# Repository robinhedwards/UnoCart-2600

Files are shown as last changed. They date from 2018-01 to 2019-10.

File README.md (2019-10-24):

UnoCart-2600
============
The UnoCart-2600 is an open source SD-card multicart for the Atari 2600. Use the joystick or the SELECT/RESET keys
to navigate the SD card and select a title to play.

SD card should be formatted as FAT or FAT32.

The UnoCart-2600 can emulate most banking schemes with ROM sizes up to 64k and RAM sizes up to 32k.
(more description to follow)

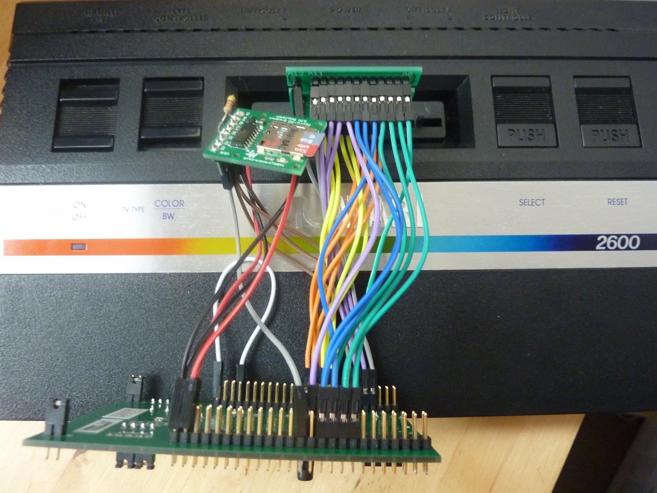
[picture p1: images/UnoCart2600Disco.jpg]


Hardware
--------
The UnoCart-2600 is based on my earlier UnoCart project for the Atari 8-bit. It can be built using a STM32F407 DISCOVERY board
connected to a small PCB to breakout the Atari 2600 cartridge signals.

An article describing how to build an UnoCart for the Atari 8-bit was published in
[Excel Magazine](http://excel-retro-mag.co.uk) issue #4. You can also get a PDF of the article [here](https://github.com/robinhedwards/UnoCart/blob/master/UnoCart_EXCEL4.pdf).

Building the cartridge for the 2600 is almost identical, with the same connections between D0-D7 and A0-A12, +5V and GND.
All the other connections to the breakout PCB can be skipped, since these signals are not present on the 2600 cartridge slot.

Obviously, you'll need a breakout board designed for the 2600 cartridge slot rather than the Atari 8-bit. The design files for the breakout PCB are hosted here and can be used to make your own copy of the PCB.

Remember to program your DISCO board with the UnoCart-2600 firmware, rather than the UnoCart firmware.

(better building instructions to follow)

The UnoCart-2600 menu can be set to display in NTSC, PAL or PAL60 as follows:
* By default, the firmware will be NTSC.
* Connect PC0 -> GND for PAL60
* Connect PC1 -> GND for PAL

Note that this is for the menu only, and has no effect after you have selected a cartridge to play.

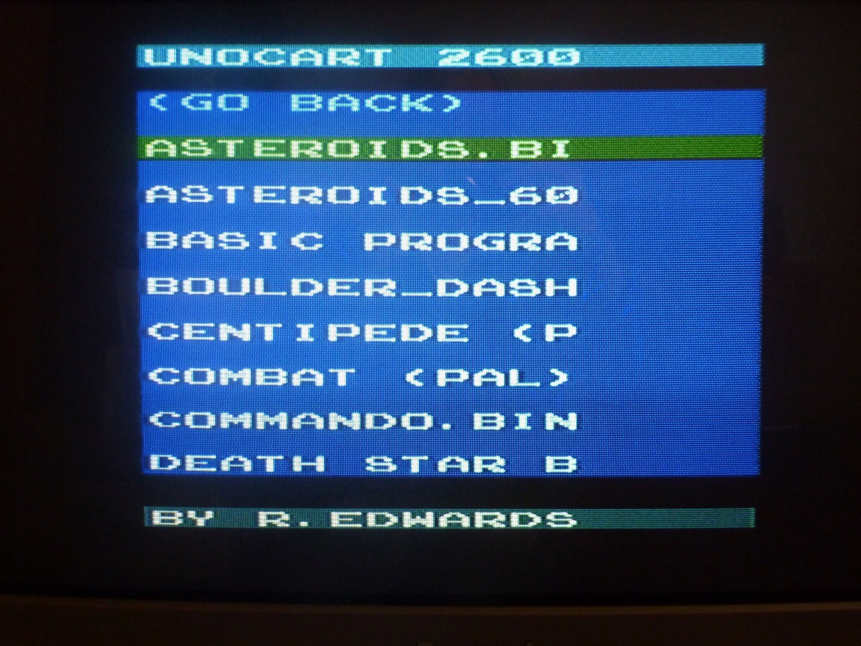
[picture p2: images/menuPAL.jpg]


Custom PCB
----------
I have also designed a custom PCB for the UnoCart-2600 pictured here. This is mainly to make it easier to get people
to test the design. The PCB design files are not currently public.

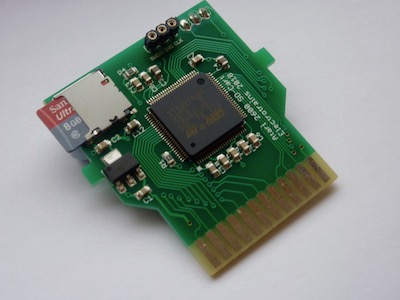
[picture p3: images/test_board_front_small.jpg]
Front of PCB when inserted in Atari

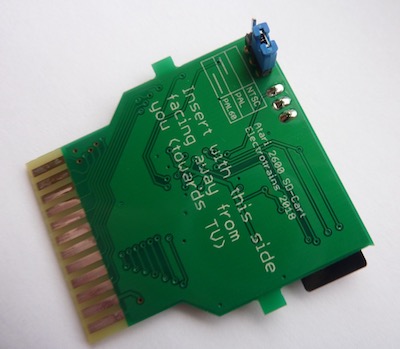
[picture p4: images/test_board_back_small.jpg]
Back of PCB when inserted in Atari


Firmware
--------
The UnoCart-2600 firmware is open source under a GPL license and my original firmware hosted here.
However, there is a newer version - see below.

New firmware
------------
I haven't had any time to develop the firmware further, but DirtyHairy & ZackAttack on the AtariAge forums
have added some great stuff to the firmware, including updating from SD card, support for Pink Panther prototype
cartridge and much more to come.

The releases of this new firmware can be found on [DirtyHairy's branch](https://github.com/DirtyHairy/UnoCart-2600/releases)

You'll need an ST-Link programmer the first time you update to this branch of the firmware. Subsequent updates can
done simply from the SD card.

Credits
-------
* Design, hardware and firmware by Robin Edwards (electrotrains at atariage)
* Additional work on firmware by Christian Speckner (DirtyHairy at atariage)

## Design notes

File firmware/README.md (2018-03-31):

The current UnoCart2600 firmware (v1.05)

For use with ST-Link device and STM32 ST-Link utility.

Changelog

* 2018-01-27 v1.0 Initial version.
* 2018-02-08 v1.02 Navigation bug fix + Pitfall II support
* 2018-03-21 v1.04 Supercharger support thanks to Christian Speckner
* 2018-03-31 v1.05 Now compatible with Atari 7800

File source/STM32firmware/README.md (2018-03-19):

Source code for the UnoCart2600 firmware.

# Building with Atollic Truestudio

Atollic Truestudio 6 project.
After building, firmware will be in the Debug subdirectory.

The various 2600 firmware ROMs (PAL/NTSC etc) are in include files. These can be rebuilt from the source code in the /source/Atari2600ROM/ directory. The convert.bat batch file will turn the binary files into header files. Add the "const" keyword so these will be stored in STM32F4 flash rather than RAM.

# Building from CLI

You can build and flash the firmware with the provided `Makefile`using the official
[ARM Cortex GNU toolchain](http://developer.arm.com/open-source/gnu-toolchain/gnu-rm)
and the open source [stlink tool suite](https://github.com/texane/stlink).

```
    $ make           # Build firware in build directory
    $ make flash     # Build and flash firmware
```

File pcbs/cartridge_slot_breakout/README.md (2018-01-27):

Eagle board file for Atari 2600 cartridge slot breakout PCB, which breaks out the cartridge slot to headers (male or female).

IMPORTANT - Make sure you insert the board the correct way round in your 2600. The picture below shows the correct orientation.

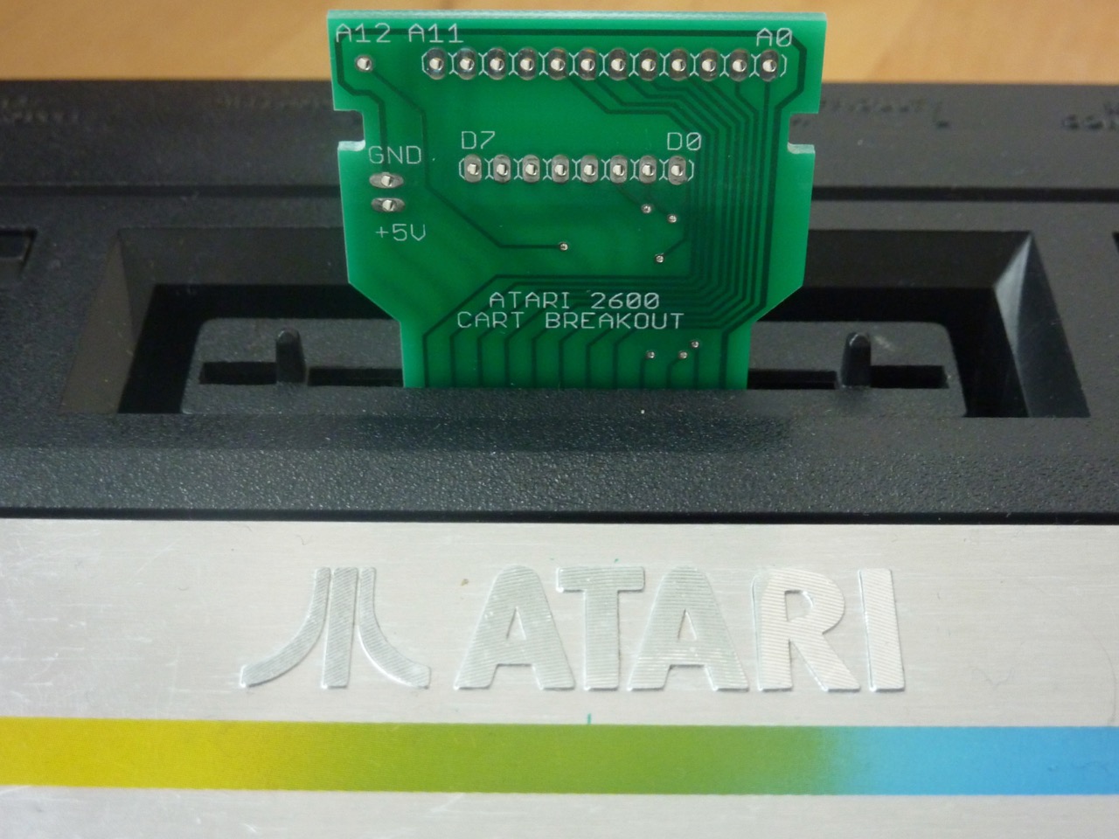
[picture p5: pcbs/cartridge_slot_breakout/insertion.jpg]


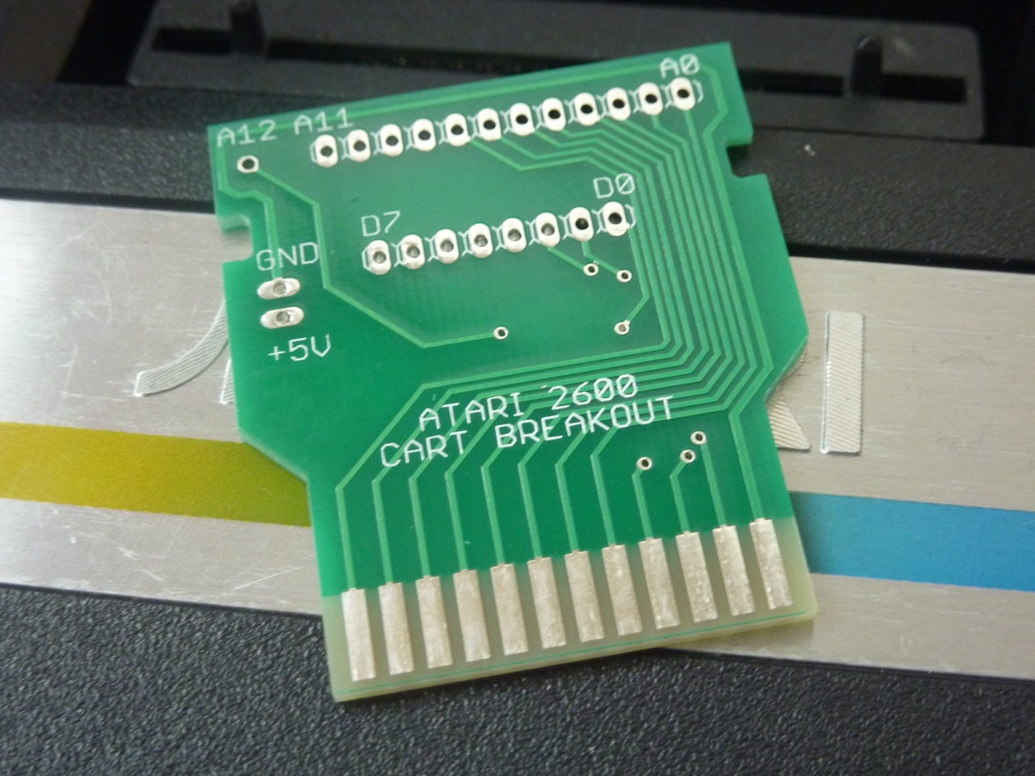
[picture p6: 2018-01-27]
images/breakout.jpg

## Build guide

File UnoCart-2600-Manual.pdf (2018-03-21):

# UNOCART-2600

# Instruction Manual

Revision 1.4 21/3/2018

Atari 2600 SD multi-cart

Quick Start
The UnoCart -2600 is an Atari cartridge emulator. It supports cartridges with up to 64k of ROM and 32k of RAM. First, copy BIN, ROM or A26 files to an SD card and insert it into the cartridge. Check the TV configuration jumper on the back of the board matches your TV system. Insert the cartridge in the Atari 2600. If the board is uncased, check you’ve got it the right way round (see picture). Power on the Atari and use the joystick to choose an item and the fire button to start it.

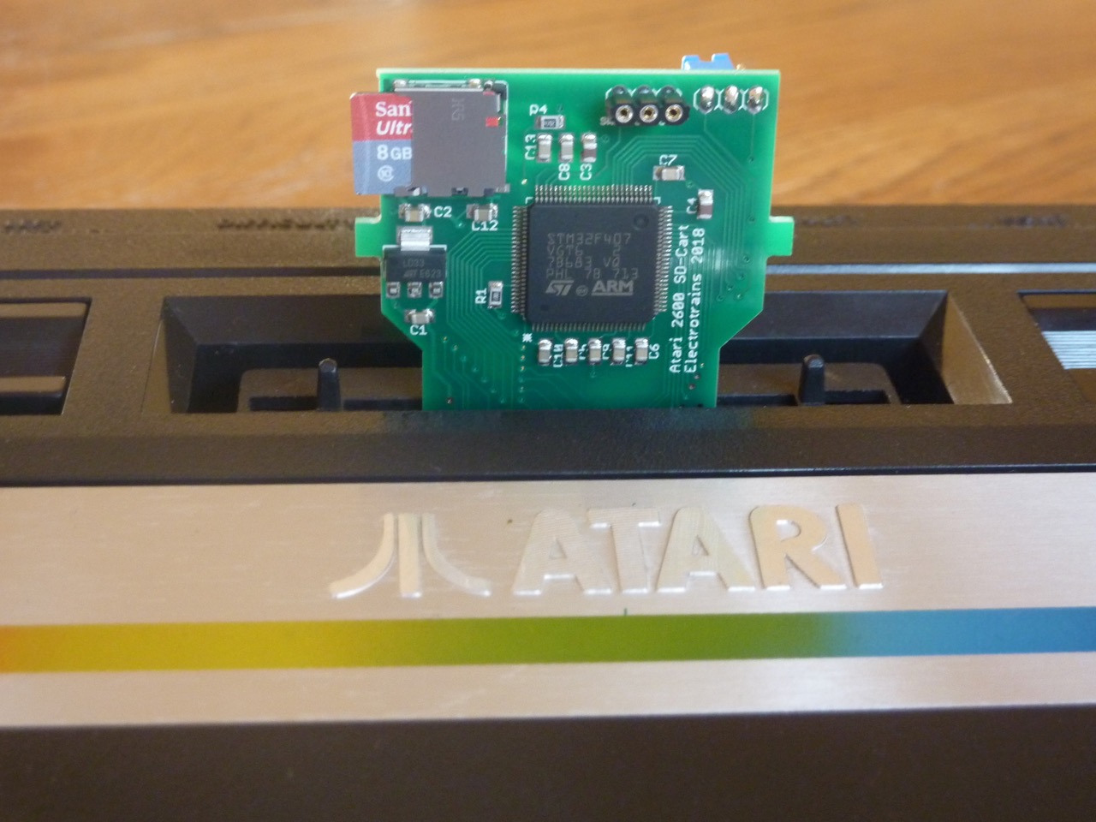
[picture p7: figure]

PAL/NTSC Configuration
The jumper on the back of the board allows you to select whether the cartridge uses NTSC or PAL/PAL60 for the built-in menu. You can remove the jumper completely if you are using a NTSC TV.
Note that this jumper only applies to the cartridge menu (and also to the Supercharger BIOS if you are using a Supercharger cartridge type). Once you select a ROM to emulate, the TV picture produced will be entirely dependent on the cartridge being emulated. In general there were separate PAL and NTSC versions of each cartridge – make sure you get the correct version.
SD Cards
SD cards should be formatted as FAT32. Newer SD cards may come formatted as exFAT. These can be used with the UnoCart-2600, but need to be re-formatted as FAT32 on your computer prior to use. Note that the UnoCart-2600 firmware will only show up to 80 items per directory. You can use directories to organise your files.

Menu

The menu allows you to navigate the files on the card and select a title to use. Joystick up and down will move through the items one at a time. You can also use joystick left and right to move to the previous or next page. Press fire to select an item. You can also use the SELECT button on the console to move to the next item, and RESET to select an item, if you don’t have a joystick plugged in.
Compatibility

The UnoCart-2600 should be able to emulate every cartridge released during the commercial life of the 2600. Newer homebrew titles should also be compatible with the UnoCart-2600, unless they use the DPC+ co-processor features specific to the Harmony/Melody cartridge. Note that the DPC support on the cartridge is not complete but it is sufficient to play Pitfall II.
Arcadia/Starpath Supercharger titles are emulated with the multi-load parts combined in a single file. Up to 256 loads are supported (2MB file). The Supercharger BIOS will use the TV type set by the UnoCart-2600 TV jumper. ROM Files

The UnoCart uses cartridge detection signatures from the Stella Atari 2600 emulator to auto-detect all common cartridge types. If a file has an extension of .BIN, .ROM or .A26 it will be auto-detected. If you want to force the cartridge to be emulated as a specific type, you can use the file extensions listed in the table below.

Cartridge Type | ROM | RAM | File Extension
2K | 2K | | .2K
4K | 4K | | .4K
F8 | 8K | | .F8
F8 SC | 8K | 128 bytes | .F8S
F6 | 16K | | .F6
F6 SC | 16K | 128 bytes | .F6S
F4 | 32K | | .F4
F4 SC | 32K | 128 bytes | .F4S
FE (Activision) | 8K | | .FE
3F (Tigervision) | <=64K | | .3F
3E | <=64K | <=32K | .3E
E0 (Parker Bros) | 8K | | .E0
0840 | 8K | | .084
CV (CommaVid) | 2K | 1K | .CV
EF | 64K | | .EF
EF SC | 64K | 128 bytes | .EFS
F0 | 64K | | .F0
FA (CBS RAM Plus) | 12K | 256 bytes | .FA
E7 (M-Network) | 16K | 2K | .E7
DPC (Pitfall II) | 8K+2K | | .DPC
Supercharger | 256 loads | | .AR

Firmware re-programming (advanced)

The board can be re-programmed using an ST-Link device. The programming header is at the top of the board. First connect the 3 pins to the equivalent pins on your ST-Link. You should then connect the ST-Link device to the USB port of your computer. You will also need to power the board – the easiest way to do this is to plug the board into your Atari 2600 and power on. The ST-Link software should then be able to connect to the STM32F407 and re-program the firmware.
The latest firmware is available on the project website: https://github.com/robinhedwards/UnoCart-2600

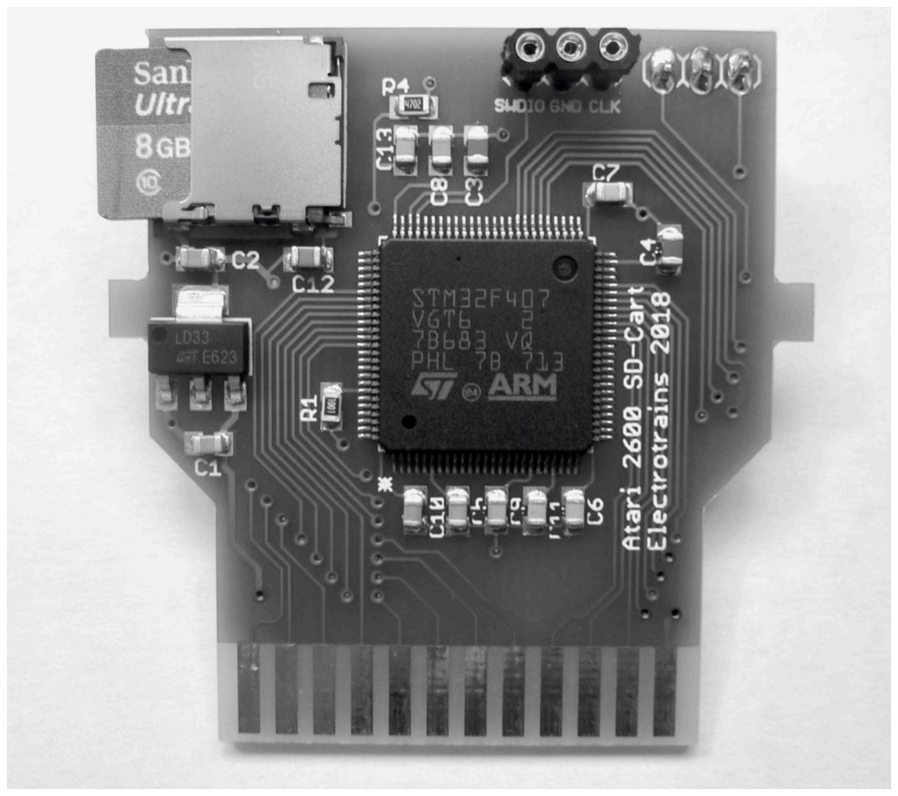
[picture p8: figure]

Pin | SWD | Function
1 | SWDIO | SWD I/O
2 | GND | GND
3 | SWCLK | SWD Clock

Microcontroller (advanced)
The UnoCart-2600 will be fitted with either a STM32F407VGT6 (1meg flash) or a STM32F407VET6 (512k flash) microcontroller. Please refer to your PCB to determine which one is present on your device. If you are developing new firmware for the cartridge, the table below shows the pins connected to the cartridge port & micro SD card slot.
STM32 Pin(s) | Cartridge Port | STM32 Pin(s) | Function
PD0...12 | A0…A12 | PB5 | MicroSD CS
PE8…15 | D0…D7 | PB13 (SPI2,2) | MicroSD CLK
PC0 | TV Jumper | PB14 (SPI2,2) | MicroSD DO
PC1 | TV Jumper | PB15 (SPI2,2) | MicroSD DI

Credits
Original idea, hardware and firmware by Robin Edwards (electrotrains at atariage).
Additional cartridge support and firmware additions by Christian Speckner (DirtyHairy at atariage).

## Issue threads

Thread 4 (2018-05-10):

Will the PCB files be made public?

Arduingo, 2018-05-10:
Great work, and thanks to make it public, are you going to release de PCB files? in case no, do you mind if someone else release his PCB design and link to this project?

robinhedwards, 2018-05-11:
The PCB design will be made public at some point in the future - I've been redesigning it to fit in a cart shell and use an SD card rather than a microSD.

These will initially be produced by MacRorie in the USA for sale, and possibly someone in europe too.
I'll update the page when this happens.

root42, 2019-05-20:
Would love to see this happen, or have the ability to buy it from someone in Europe. Any chance of progress on this?

ranger81, 2020-04-03:
@robinhedwards Is there any update on releasing the PCB files or schematics?
Thanks

TabajaraLabs, 2020-04-03:
Looking for the PCB files too =)

tdididit, 2020-04-03:
@robinhedwards If you agree I will make public my PCB design with USB ISP circuit addon

ranger81, 2020-04-03:
@tdididit Would be greatly appreciated. Schematic would be fine for me - also I would be very interested about the USB ISP circuit addon. Please let me know, if your schematics are available somewhere.

tdididit, 2020-04-03:
@ranger81 I didn't seen a schematics, but only thing what you need to make it is reading with understanding UnoCart2600 manual file. Like I wrote before I can make my github repository public if @robinhedwards will agree

mase76, 2022-09-01:
Can you publish the schematics?

manotroll, 2022-09-15:
up

manotroll, 2024-01-13:
?

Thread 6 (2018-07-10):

Support a psuedo-reset button

unwiredben, 2018-07-10:
A feature that seems doable would be to have a pseudo-reset button on the board hooked up to a GPIO and pull-up resistor which would cause the firmware to start sending a series of BRK instructions until the button was released, upon which the cart would start serving the menu program.  This would save wear-and-tear on the power switch on the console and allow switching games quicker.

unwiredben, 2018-09-17:
Yes, it was a way to getting the currently running 6502 code on the 2600 back into a known state, although that might not be sufficient to act like a just powered-on 2600.  Most games will init everything to the state they want, but I know some make assumptions about the state of RAM that wouldn't hold in this situation.

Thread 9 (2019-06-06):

Add information about custom pcb availability

FabienTregan, 2019-06-06:
Hi,

  the readme.md tells about the custom pcb that looks fantastic, but gives no information about if it currently available and where to buy it. I want one :)

  Thanks for great work !

robinhedwards, 2019-06-13:
Hi Fabian,

Sorry I should update the readme!
You can get an assembled cartridge from MacRorie in the USA. He makes and
sells them on my behalf.
https://thebrewingacademy.com/

regards,

Robin

On Thu, Jun 6, 2019 at 7:15 PM Fabien Tregan <notifications@github.com>
wrote:

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

--
Robin Edwards
email: robin.edwards@gmail.com
Tel: +44(0)1875 853 667
Mob: +44(0)7989 345 150

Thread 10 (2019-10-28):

CANT

andrew-davie, 2019-10-28:
Not sure which version I'm running - just got the UnoCart as a gift today.
It's probably a very old version but in any case, this is the "bug"...

When there is no SD card, it says something like "CANT LOAD SD"
There needs to be an apostrophe.  "CAN'T" not "CANT"
I know it's minor, but these things bug me :P

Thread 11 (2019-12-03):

new funny new question

darleiv, 2019-12-03:
hello, that's cool, friend, I'm a fan of your project. I really have some doubts. SWDIO is connected to the correct ARM pin PA13. but I can't know where is the CLK you used. because I do not have a software to read your pin firmware if you can help where I connect clk would appreciate

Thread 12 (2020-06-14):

Issues with my build

Spyke1975, 2020-06-14:
Thank you for sharing this nice work!
I build a cart, but it didn´t work correct. I build this version:
https://circuit-board.de/forum/index.php/Thread/26071-UnoCart-2600-ein-Selbstbau-SD-Karten-Atari-2600-bzw-7800-Modul/
with the black Chinese STM32F4XX.
The cart boots and I can see the menue for a short time, it also reads my SD, because I can see the content. But after a few seconds it ens up in blue screen.
Any ideas what the problem is?

Thanks in advance and best regards
Marc

robinhedwards, 2020-06-15:
Hi Marc,

Does it always blue screen at the same point? Maybe check your jumper wires
- I've had issues like this before with bad connections/partially broken
wires.

Robin

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

--
Robin Edwards
email: robin.edwards@gmail.com
Tel: +44(0)1620 880 345
Mob: +44(0)7989 345 150

Spyke1975, 2020-06-15:
Hi Robin,

rhanks for reply.
yes it's allways at the same point.
2 or 3 seconds after the menu appears.
I checked all conections and they seem to be ok. Do you think the Problem is in the connections for the board or the SD-modul?

In the short time I have tried to start a game and it works, but end up in blue scrreen. Maybe the board is faulty.
Marc

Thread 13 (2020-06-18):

Display only "SD" on blue screen

ranger81, 2020-06-18:
I have built an UnoCart and flashed the latest binary. Without plugged in SD-Cart, the menu shows up and displays "CANT READ SD", so far so good.
When I insert the SD Cart (FAT32), the screen is filled in blue and displays only "SD" in big letters.

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

Do you have any advice, what could be wrong?

Thanks!

robinhedwards, 2020-06-19:
As a first step, it's probably worth trying a different SD card with only a
few files on it.

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

--
Robin Edwards
email: robin.edwards@gmail.com
Tel: +44(0)1620 880 345
Mob: +44(0)7989 345 150

ranger81, 2020-06-28:
Thanks for you support, I ordered some STM32F407 but got STM32F207 delivered. Didn't check them before soldering. Now I got proper STM32F407 and it works as expected. Sorry to bother you!

robinhedwards, 2020-06-28:
Okay, I would never have guessed you'd done that! Glad you got it working.

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

--
Robin Edwards
email: robin.edwards@gmail.com
Tel: +44(0)1620 880 345
Mob: +44(0)7989 345 150

Closed 2020-06-28.

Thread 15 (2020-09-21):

Could You add paddle support for scroll and select in SD card list

NuClear235, 2020-09-21:
Hello,
Could You please add paddle supportfor scroll and select in SD list?
Thank You

thrust26, 2020-09-21:
Paddle control is pretty complicate for many people to use (see Harmony cart). Therefore I added console switches and a joystick in **right** port to the Harmony controls.

DirtyHairy, 2020-09-21:
I want to eventually adapt Thomas' high res display kernel from the PlusCart menu to the Uno. I'll probably add paddle support when I do this.

NuClear235, 2020-09-22:
Good news. I will looking forward to it :-)

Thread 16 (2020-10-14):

Feature Request: In Game Reset

tjstogy, 2020-10-14:
Similar to many other available flashcarts (but not Atari yet!) it would be great if there was a way to go back to the main menu while in a game, with a button combination. Obviously the buttons are limited, so perhaps holding the fire button and a direction for 3 seconds would suffice. Thanks for the awesome product

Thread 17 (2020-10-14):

Feature Request: Scrolling Titles

tjstogy, 2020-10-14:
Some titles are much too long to fit on the screen (especially hacks). Would it be possible to implement scrolling text when hovering over a title, or something similar?

thrust26, 2020-10-14:
I suggest using the Harmony way here:
- game/folder selection etc. happens on button **release**
- this allows for a long button press (e.g. 1s) , which loads a new screen which displays the whole filename (on button release, the previous screen gets displayed)

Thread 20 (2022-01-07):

Is there an STL file available?

jgrillout, 2022-01-07:
I'm new to this whole UniCart product. It is very cool. I want to 3d print my own cartridge. Is there a STL file available?  Also where can I buy the rest of the hardware for this project. I saw a video, I can't remember if it was for Uni or harmony, that mentioned the project became open source. Does this apply to code only or hardware too?

Thank you,
John

ojaksch, 2022-01-07:
Can't remember where my case came from but found this: https://www.thingiverse.com/thing:4580701

jgrillout, 2022-01-07:
thanks Larry !

and-pad, 2022-04-05:
> I'm new to this whole UniCart product. It is very cool. I want to 3d print my own cartridge. Is there a STL file available? Also where can I buy the rest of the hardware for this project. I saw a video, I can't remember if it was for Uni or harmony, that mentioned the project became open source. Does this apply to code only or hardware too?
>
> Thank you, John

Hi John, I have finished some parts and it works, if you are still interested, I don't know if you have got the drawing of the atari cartridge.
If you are interested I leave you my email: andrestor@gmail.com
Andres Padilla

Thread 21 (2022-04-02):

Hardware alternative?

Lalarian, 2022-04-02:
Hello!

As the Stm32f407 dev board has become expensive (35€ including shipping for the cheapest offer I could find), I wonder if there's an more affordable alternative hardware which the firmware could easily be translated, to?

darleiv, 2022-06-18:
@DirtyHairy

darleiv, 2022-06-18:
@DirtyHairy

darleiv, 2022-06-18:
@robinhedwards

MrGasS, 2022-11-08:
I was thinking the same thing, an STM32 BluePill port would be beautiful as the Discovery board is crazy expensive.

gtortone, 2023-07-08:
Hi,
in next weeks I will start to work (in my spare time) on a porting for ESP32 based on ESP32-S2-mini that is widely
available on online stores at very low price. I have in plan to design a board with 5V - 3.3V level converter and a "socket" to plug-in ESP32-S2-mini board...

MrGasS, 2023-07-09:
> Hi, in next weeks I will start to work (in my spare time) on a porting for ESP32 based on ESP32-S2-mini that is widely available on online stores at very low price. I have in plan to design a board with 5V - 3.3V level converter and a "socket" to plug-in ESP32-S2-mini board...

thank you a lot, can't wait to see your ESP32 port :)
(Forza Napoli)

manotroll, 2024-01-13:
Raspberry Pi Pico does not directly support up to 30V
and wouldn't it still be cheaper than an esp32?

gtortone, 2024-04-19:
Hi,
if you are interested to this development, I completed Raspberry Pico porting of PlusCart:

https://github.com/gtortone/United-Carts-of-Atari

manotroll, 2024-04-19:
> Hi, if you are interested to this development, I completed Raspberry Pico porting of PlusCart:
>
> https://github.com/gtortone/United-Carts-of-Atari

Do you have a list of the components that are used?
and there is no way to use the SD or wifi?

gtortone, 2024-04-20:
@manotroll the PlusCart with RP2040 provides microSD and wifi interface. For wifi it uses the default PlusCart store called PlusStore where you will find hundreds of classic games and homebrew for Atari 2600...

to build a PlusCart board with RP2040 you need

- a Raspberry Pico board, not the "green" because a "purple" one exists (look on AliExpress) that has more pins available on header
- a microSD breakout board (Amazon or AliExpress)
- an ESP-01 module (Amazon or AliExpress)

In a few days I will write some documentation on the GitHub repository (pinout, build instructions, ...), but in the meanwhile let me know if you need help !

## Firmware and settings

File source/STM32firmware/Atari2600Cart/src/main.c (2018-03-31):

/*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
 * You should have received a copy of the GNU General Public License
 * along with this program.  If not, see <http://www.gnu.org/licenses/>.
 */

/* Version History
 * ---------------
 * v1.01 5/2/18 Fixed menu navigation bug after selecting a bad rom file
 * v1.02 8/2/18 Added partial DPC support - Pitfall II works
 * v1.03 19/3/18 Supercharger support thanks to Christian Speckner
 * v1.04 21/3/18 Bug fixes (file extension->cart type)
 * v1.05 29/3/18 Firmware compatible with the 7800 bios
 */

#define _GNU_SOURCE

#include "defines.h"
#include "stm32f4xx.h"
#include "tm_stm32f4_fatfs.h"
#include "tm_stm32f4_delay.h"

#include <ctype.h>

#include "cartridge_io.h"
#include "cartridge_firmware.h"
#include "cartridge_supercharger.h"

/*************************************************************************
 * Cartridge Definitions
 *************************************************************************/
#define MAX_CART_ROM_SIZE	64	// in kilobytes, historical to be removed
#define MAX_CART_RAM_SIZE	32	// in kilobytes, historical to be removed
#define BUFFER_SIZE			96  // kilobytes

uint8_t buffer[BUFFER_SIZE * 1024];

char cartridge_image_path[256];
unsigned int cart_size_bytes;
int tv_mode;

#define CART_TYPE_NONE	0
#define CART_TYPE_2K	1
#define CART_TYPE_4K	2
#define CART_TYPE_F8	3	// 8k
#define CART_TYPE_F6	4	// 16k
#define CART_TYPE_F4	5	// 32k
#define CART_TYPE_F8SC	6	// 8k+ram
#define CART_TYPE_F6SC	7	// 16k+ram
#define CART_TYPE_F4SC	8	// 32k+ram
#define CART_TYPE_FE	9	// 8k
#define CART_TYPE_3F	10	// varies (examples 8k)
#define CART_TYPE_3E	11	// varies (only example 32k)
#define CART_TYPE_E0	12	// 8k
#define CART_TYPE_0840	13	// 8k
#define CART_TYPE_CV	14	// 2k+ram
#define CART_TYPE_EF	15	// 64k
#define CART_TYPE_EFSC	16	// 64k+ram
#define CART_TYPE_F0	17	// 64k
#define CART_TYPE_FA	18	// 12k
#define CART_TYPE_E7	19	// 16k+ram
#define CART_TYPE_DPC	20	// 8k+DPC(2k)
#define CART_TYPE_AR	21  // Arcadia Supercharger (variable size)

typedef struct {
	const char *ext;
	int cart_type;
} EXT_TO_CART_TYPE_MAP;

EXT_TO_CART_TYPE_MAP ext_to_cart_type_map[] = {
	{"ROM", CART_TYPE_NONE},
	{"BIN", CART_TYPE_NONE},
	{"A26", CART_TYPE_NONE},
	{"2K", CART_TYPE_2K},
	{"4K", CART_TYPE_4K},
	{"F8", CART_TYPE_F8},
	{"F6", CART_TYPE_F6},
	{"F4", CART_TYPE_F4},
	{"F8S", CART_TYPE_F8SC},
	{"F6S", CART_TYPE_F6SC},
	{"F4S", CART_TYPE_F4SC},
	{"FE", CART_TYPE_FE},
	{"3F", CART_TYPE_3F},
	{"3E", CART_TYPE_3E},
	{"E0", CART_TYPE_E0},
	{"084", CART_TYPE_0840},
	{"CV", CART_TYPE_CV},
	{"EF", CART_TYPE_EF},
	{"EFS", CART_TYPE_EFSC},
	{"F0", CART_TYPE_F0},
	{"FA", CART_TYPE_FA},
	{"E7", CART_TYPE_E7},
	{"DPC", CART_TYPE_DPC},
	{"AR", CART_TYPE_AR},
	{0,0}
};

/*************************************************************************
 * Cartridge Type Detection
 *************************************************************************/

/* The following detection routines are modified from the Atari 2600 Emulator Stella
  (https://github.com/stella-emu) */

int isProbablySC(int size, unsigned char *bytes)
{
	int banks = size/4096;
	for (int i = 0; i < banks; i++)
	{
		for (int j = 0; j < 128; j++)
		{
			if (bytes[i*4096+j] != bytes[i*4096+j+128])
				return 0;
		}
	}
	return 1;
}

int searchForBytes(unsigned char *bytes, int size, unsigned char *signature, int sigsize, int minhits)
{
	int count = 0;
	for(int i = 0; i < size - sigsize; ++i)
	{
		int matches = 0;
		for(int j = 0; j < sigsize; ++j)
		{
			if(bytes[i+j] == signature[j])
				++matches;
			else
				break;
		}
		if(matches == sigsize)
		{
			++count;
			i += sigsize;  // skip past this signature 'window' entirely
		}
		if(count >= minhits)
			break;
	}
	return (count >= minhits);
}

int isProbablyFE(int size, unsigned char *bytes)
{	// These signatures are attributed to the MESS project
	unsigned char signature[4][5] = {
		{ 0x20, 0x00, 0xD0, 0xC6, 0xC5 },  // JSR $D000; DEC $C5
		{ 0x20, 0xC3, 0xF8, 0xA5, 0x82 },  // JSR $F8C3; LDA $82
		{ 0xD0, 0xFB, 0x20, 0x73, 0xFE },  // BNE $FB; JSR $FE73
		{ 0x20, 0x00, 0xF0, 0x84, 0xD6 }   // JSR $F000; STY $D6
	};
	for (int i = 0; i < 4; ++i)
		if(searchForBytes(bytes, size, signature[i], 5, 1))
			return 1;

	return 0;
}

int isProbably3F(int size, unsigned char *bytes)
{	// 3F cart bankswitching is triggered by storing the bank number
	// in address 3F using 'STA $3F'
	// We expect it will be present at least 2 times, since there are
	// at least two banks
	unsigned char signature[] = { 0x85, 0x3F };  // STA $3F
	return searchForBytes(bytes, size, signature, 2, 2);
}

int isProbably3E(int size, unsigned char *bytes)
{	// 3E cart bankswitching is triggered by storing the bank number
	// in address 3E using 'STA $3E', commonly followed by an
	// immediate mode LDA
	unsigned char  signature[] = { 0x85, 0x3E, 0xA9, 0x00 };  // STA $3E; LDA #$00
	return searchForBytes(bytes, size, signature, 4, 1);
}

int isProbablyE0(int size, unsigned char *bytes)
{	// E0 cart bankswitching is triggered by accessing addresses
	// $FE0 to $FF9 using absolute non-indexed addressing
	// These signatures are attributed to the MESS project
	unsigned char signature[8][3] = {
			{ 0x8D, 0xE0, 0x1F },  // STA $1FE0
			{ 0x8D, 0xE0, 0x5F },  // STA $5FE0
			{ 0x8D, 0xE9, 0xFF },  // STA $FFE9
			{ 0x0C, 0xE0, 0x1F },  // NOP $1FE0
			{ 0xAD, 0xE0, 0x1F },  // LDA $1FE0
			{ 0xAD, 0xE9, 0xFF },  // LDA $FFE9
			{ 0xAD, 0xED, 0xFF },  // LDA $FFED
			{ 0xAD, 0xF3, 0xBF }   // LDA $BFF3
		};
	for (int i = 0; i < 8; ++i)
		if(searchForBytes(bytes, size, signature[i], 3, 1))
			return 1;
	return 0;
}

int isProbably0840(int size, unsigned char *bytes)
{	// 0840 cart bankswitching is triggered by accessing addresses 0x0800
	// or 0x0840 at least twice
	unsigned char signature1[3][3] = {
			{ 0xAD, 0x00, 0x08 },  // LDA $0800
			{ 0xAD, 0x40, 0x08 },  // LDA $0840
			{ 0x2C, 0x00, 0x08 }   // BIT $0800
		};
	for (int i = 0; i < 3; ++i)
		if(searchForBytes(bytes, size, signature1[i], 3, 2))
			return 1;

	unsigned char signature2[2][4] = {
			{ 0x0C, 0x00, 0x08, 0x4C },  // NOP $0800; JMP ...
			{ 0x0C, 0xFF, 0x0F, 0x4C }   // NOP $0FFF; JMP ...
		};
	for (int i = 0; i < 2; ++i)
		if(searchForBytes(bytes, size, signature2[i], 4, 2))
			return 1;

	return 0;
}

int isProbablyCV(int size, unsigned char *bytes)
{ 	// CV RAM access occurs at addresses $f3ff and $f400
	// These signatures are attributed to the MESS project
	unsigned char signature[2][3] = {
			{ 0x9D, 0xFF, 0xF3 },  // STA $F3FF.X
			{ 0x99, 0x00, 0xF4 }   // STA $F400.Y
		};
	for (int i = 0; i < 2; ++i)
		if(searchForBytes(bytes, size, signature[i], 3, 1))
			return 1;
	return 0;
}

int isProbablyEF(int size, unsigned char *bytes)
{ 	// EF cart bankswitching switches banks by accessing addresses
	// 0xFE0 to 0xFEF, usually with either a NOP or LDA
	// It's likely that the code will switch to bank 0, so that's what is tested
	unsigned char signature[4][3] = {
			{ 0x0C, 0xE0, 0xFF },  // NOP $FFE0
			{ 0xAD, 0xE0, 0xFF },  // LDA $FFE0
			{ 0x0C, 0xE0, 0x1F },  // NOP $1FE0
			{ 0xAD, 0xE0, 0x1F }   // LDA $1FE0
		};
	for (int i = 0; i < 4; ++i)
		if(searchForBytes(bytes, size, signature[i], 3, 1))
			return 1;
	return 0;
}

int isProbablyE7(int size, unsigned char *bytes)
{ 	// These signatures are attributed to the MESS project
	unsigned char signature[7][3] = {
			{ 0xAD, 0xE2, 0xFF },  // LDA $FFE2
			{ 0xAD, 0xE5, 0xFF },  // LDA $FFE5
			{ 0xAD, 0xE5, 0x1F },  // LDA $1FE5
			{ 0xAD, 0xE7, 0x1F },  // LDA $1FE7
			{ 0x0C, 0xE7, 0x1F },  // NOP $1FE7
			{ 0x8D, 0xE7, 0xFF },  // STA $FFE7
			{ 0x8D, 0xE7, 0x1F }   // STA $1FE7
		};
	for (int i = 0; i < 7; ++i)
		if(searchForBytes(bytes, size, signature[i], 3, 1))
			return 1;
	return 0;
}

/*************************************************************************
 * File/Directory Handling
 *************************************************************************/

#define NUM_DIR_ITEMS	80

typedef struct {
	char isDir;
	char filename[13];
	char long_filename[32];
} DIR_ENTRY;

DIR_ENTRY dir_entries[NUM_DIR_ITEMS];

int num_dir_entries = 0; // how many entries in the current directory

int entry_compare(const void* p1, const void* p2)
{
	DIR_ENTRY* e1 = (DIR_ENTRY*)p1;
	DIR_ENTRY* e2 = (DIR_ENTRY*)p2;
	if (e1->isDir && !e2->isDir) return -1;
	else if (!e1->isDir && e2->isDir) return 1;
	else return strcasecmp(e1->long_filename, e2->long_filename);
}

char *get_filename_ext(char *filename) {
	char *dot = strrchr(filename, '.');
	if(!dot || dot == filename) return "";
	return dot + 1;
}

int is_valid_file(char *filename) {
	char *ext = get_filename_ext(filename);
	EXT_TO_CART_TYPE_MAP *p = ext_to_cart_type_map;
	while (p->ext) {
		if (strcasecmp(ext, p->ext) == 0)
			return 1;
		p++;
	}
	return 0;
}

// single FILINFO structure
FILINFO fno;
char lfn[_MAX_LFN + 1];   /* Buffer to store the LFN */

void init() {
	// this seems to be required for this version of FAT FS
	fno.lfname = lfn;
	fno.lfsize = sizeof lfn;
}

int read_directory(char *path) {
	int ret = 0;
	num_dir_entries = 0;
	DIR_ENTRY *dst = (DIR_ENTRY *)&dir_entries[0];

	FATFS FatFs;
	TM_DELAY_Init();
	if (f_mount(&FatFs, "", 1) == FR_OK) {
		DIR dir;
		if (f_opendir(&dir, path) == FR_OK) {
			if (strlen(path))
			{	// not root directory, add pseudo ".." to go up a dir
				dst->isDir = 1;
				strcpy(dst->long_filename, "(GO BACK)");
				strcpy(dst->filename, "..");
				num_dir_entries++;
				dst++;
			}
			while (num_dir_entries < NUM_DIR_ITEMS) {
				if (f_readdir(&dir, &fno) != FR_OK || fno.fname[0] == 0)
					break;
				if (fno.fattrib & (AM_HID | AM_SYS))
					continue;
				dst->isDir = fno.fattrib & AM_DIR ? 1 : 0;
				if (!dst->isDir)
					if (!is_valid_file(fno.fname)) continue;
				// copy file record
				strcpy(dst->filename, fno.fname);
				if (fno.lfname[0]) {
					strncpy(dst->long_filename, fno.lfname, 31);
					dst->long_filename[31] = 0;
				}
				else strcpy(dst->long_filename, fno.fname);
				dst++;
				num_dir_entries++;
			}
			f_closedir(&dir);
			qsort((DIR_ENTRY *)&dir_entries[0], num_dir_entries, sizeof(DIR_ENTRY), entry_compare);
			ret = 1;
		}
		f_mount(0, "", 1);
	}
	return ret;
}

int identify_cartridge(char *filename)
{
	TM_DELAY_Init();
	FATFS FatFs;
	unsigned int image_size;
	int cart_type = CART_TYPE_NONE;
	FIL fil;

	if (f_mount(&FatFs, "", 1) != FR_OK) return CART_TYPE_NONE;
	if (f_open(&fil, filename, FA_READ) != FR_OK) goto unmount;

	// select type by file extension?
	char *ext = get_filename_ext(filename);
	EXT_TO_CART_TYPE_MAP *p = ext_to_cart_type_map;
	while (p->ext) {
		if (strcasecmp(ext, p->ext) == 0) {
			cart_type = p->cart_type;
			break;
		}
		p++;
	}

	image_size = f_size(&fil);

	// Supercharger cartridges get special treatment, since we don't load the entire
	// file into the buffer here
	if (cart_type == CART_TYPE_NONE && (image_size % 8448) == 0)
		cart_type = CART_TYPE_AR;
	if (cart_type == CART_TYPE_AR) goto close;

	// otherwise, read the file into the cartridge buffer
	unsigned int bytes_to_read = image_size > (BUFFER_SIZE * 1024) ? (BUFFER_SIZE * 1024) : image_size;
	UINT bytes_read;
	FRESULT read_result = f_read(&fil, buffer, bytes_to_read, &bytes_read);

	if (read_result != FR_OK || bytes_to_read != bytes_read) {
		cart_type = CART_TYPE_NONE;
		goto close;
	}

	if (cart_type != CART_TYPE_NONE) goto close;

	// If we don't already know the type (from the file extension), then we
	// auto-detect the cart type - largely follows code in Stella's CartDetector.cpp
	if (image_size == 2*1024)
	{
		if (isProbablyCV(bytes_read, buffer))
			cart_type = CART_TYPE_CV;
		else
			cart_type = CART_TYPE_2K;
	}
	else if (image_size == 4*1024)
	{
		cart_type = CART_TYPE_4K;
	}
	else if (image_size == 8*1024)
	{
		// First check for *potential* F8
		unsigned char  signature[] = { 0x8D, 0xF9, 0x1F };  // STA $1FF9
		int f8 = searchForBytes(buffer, bytes_read, signature, 3, 2);

		if (isProbablySC(bytes_read, buffer))
			cart_type = CART_TYPE_F8SC;
		else if (memcmp(buffer, buffer + 4096, 4096) == 0)
			cart_type = CART_TYPE_4K;
		else if (isProbablyE0(bytes_read, buffer))
			cart_type = CART_TYPE_E0;
		else if (isProbably3E(bytes_read, buffer))
			cart_type = CART_TYPE_3E;
		else if (isProbably3F(bytes_read, buffer))
			cart_type = CART_TYPE_3F;
		else if (isProbablyFE(bytes_read, buffer) && !f8)
			cart_type = CART_TYPE_FE;
		else if (isProbably0840(bytes_read, buffer))
			cart_type = CART_TYPE_0840;
		else
			cart_type = CART_TYPE_F8;
	}
	else if(image_size >= 10240 && image_size <= 10496)
	{  // ~10K - Pitfall II
		cart_type = CART_TYPE_DPC;
	}
	else if (image_size == 12*1024)
	{
		cart_type = CART_TYPE_FA;
	}
	else if (image_size == 16*1024)
	{
		if (isProbablySC(bytes_read, buffer))
			cart_type = CART_TYPE_F6SC;
		else if (isProbablyE7(bytes_read, buffer))
			cart_type = CART_TYPE_E7;
		else if (isProbably3E(bytes_read, buffer))
			cart_type = CART_TYPE_3E;
		else
			cart_type = CART_TYPE_F6;
	}
	else if (image_size == 32*1024)
	{
		if (isProbablySC(bytes_read, buffer))
			cart_type = CART_TYPE_F4SC;
		else if (isProbably3E(bytes_read, buffer))
			cart_type = CART_TYPE_3E;
		else if (isProbably3F(bytes_read, buffer))
			cart_type = CART_TYPE_3F;
		else
			cart_type = CART_TYPE_F4;
	}
	else if (image_size == 64*1024)
	{
		if (isProbably3E(bytes_read, buffer))
			cart_type = CART_TYPE_3E;
		else if (isProbably3F(bytes_read, buffer))
			cart_type = CART_TYPE_3F;
		else if (isProbablyEF(bytes_read, buffer))
		{
			if (isProbablySC(bytes_read, buffer))
				cart_type = CART_TYPE_EFSC;
			else
				cart_type = CART_TYPE_EF;
		}
		else
			cart_type = CART_TYPE_F0;
	}

	close:
		f_close(&fil);

	unmount:
		f_mount(0, "", 1);

	if (cart_type)
		cart_size_bytes = image_size;

	return cart_type;
}

/*************************************************************************
 * MCU Initialisation
 *************************************************************************/

GPIO_InitTypeDef  GPIO_InitStructure;

/* Input/Output data GPIO pins on PE{8..15} */
void config_gpio_data(void) {
	/* GPIOE Periph clock enable */
	RCC_AHB1PeriphClockCmd(RCC_AHB1Periph_GPIOE, ENABLE);

	/* Configure GPIO Settings */
	GPIO_InitStructure.GPIO_Pin =
		GPIO_Pin_8 | GPIO_Pin_9 | GPIO_Pin_10 | GPIO_Pin_11 |
		GPIO_Pin_12 | GPIO_Pin_13 | GPIO_Pin_14 | GPIO_Pin_15;
	GPIO_InitStructure.GPIO_Mode = GPIO_Mode_IN;
	GPIO_InitStructure.GPIO_OType = GPIO_OType_PP;
	GPIO_InitStructure.GPIO_Speed = GPIO_Speed_25MHz;
	GPIO_InitStructure.GPIO_PuPd = GPIO_PuPd_NOPULL;
	GPIO_Init(GPIOE, &GPIO_InitStructure);
}

/* Input Address GPIO pins on PD{0..15} */
void config_gpio_addr(void) {
	/* GPIOD Periph clock enable */
	RCC_AHB1PeriphClockCmd(RCC_AHB1Periph_GPIOD, ENABLE);

	/* Configure GPIO Settings */
	GPIO_InitStructure.GPIO_Pin =
		GPIO_Pin_0 | GPIO_Pin_1 | GPIO_Pin_2 | GPIO_Pin_3 |
		GPIO_Pin_4 | GPIO_Pin_5 | GPIO_Pin_6 | GPIO_Pin_7 |
		GPIO_Pin_8 | GPIO_Pin_9 | GPIO_Pin_10 | GPIO_Pin_11 |
		GPIO_Pin_12 | GPIO_Pin_13 | GPIO_Pin_14 | GPIO_Pin_15;
	GPIO_InitStructure.GPIO_Mode = GPIO_Mode_IN;
	GPIO_InitStructure.GPIO_OType = GPIO_OType_PP;
	GPIO_InitStructure.GPIO_Speed = GPIO_Speed_100MHz;
	GPIO_InitStructure.GPIO_PuPd = GPIO_PuPd_DOWN;
	GPIO_Init(GPIOD, &GPIO_InitStructure);
}

/* Input Signals GPIO pins - PC0, PC1 (PC0=0 PAL60, PC1=0 PAL) */
void config_gpio_sig(void) {
	/* GPIOC Periph clock enable */
	RCC_AHB1PeriphClockCmd(RCC_AHB1Periph_GPIOC, ENABLE);

	/* Configure GPIO Settings */
	GPIO_InitStructure.GPIO_Pin = GPIO_Pin_0 | GPIO_Pin_1;
	GPIO_InitStructure.GPIO_Mode = GPIO_Mode_IN;
	GPIO_InitStructure.GPIO_OType = GPIO_OType_PP;
	GPIO_InitStructure.GPIO_Speed = GPIO_Speed_25MHz;
	GPIO_InitStructure.GPIO_PuPd = GPIO_PuPd_UP;
	GPIO_Init(GPIOC, &GPIO_InitStructure);
}

/*************************************************************************
 * Cartridge Emulation
 *************************************************************************/

#define setup_cartridge_image() \
	if (cart_size_bytes > 0x010000) return; \
	uint8_t* cart_rom = buffer; \
	if (!reboot_into_cartridge()) return;

#define setup_cartridge_image_with_ram() \
	if (cart_size_bytes > 0x010000) return; \
	uint8_t* cart_rom = buffer; \
	uint8_t* cart_ram = buffer + cart_size_bytes + (((~cart_size_bytes & 0x03) + 1) & 0x03); \
	if (!reboot_into_cartridge()) return;

void emulate_2k_cartridge() {
	setup_cartridge_image();

	__disable_irq();	// Disable interrupts
	uint16_t addr, addr_prev = 0;
	while (1)
	{
		while ((addr = ADDR_IN) != addr_prev)
			addr_prev = addr;
		// got a stable address
		if (addr & 0x1000)
		{ // A12 high
			DATA_OUT = ((uint16_t)cart_rom[addr&0x7FF])<<8;
			SET_DATA_MODE_OUT
			// wait for address bus to change
			while (ADDR_IN == addr) ;
			SET_DATA_MODE_IN
		}
	}
	__enable_irq();
}

void emulate_4k_cartridge() {
	setup_cartridge_image();

	__disable_irq();	// Disable interrupts
	uint16_t addr, addr_prev = 0;
	while (1)
	{
		while ((addr = ADDR_IN) != addr_prev)
			addr_prev = addr;
		// got a stable address
		if (addr & 0x1000)
		{ // A12 high
			DATA_OUT = ((uint16_t)cart_rom[addr&0xFFF])<<8;
			SET_DATA_MODE_OUT
			// wait for address bus to change
			while (ADDR_IN == addr) ;
			SET_DATA_MODE_IN
		}
	}
	__enable_irq();
}

/* 'Standard' Bankswitching
 * ------------------------
 * Used by F8(8k), F6(16k), F4(32k), EF(64k)
 * and F8SC(8k), F6SC(16k), F4SC(32k), EFSC(64k)
 *
 * SC variants have 128 bytes of RAM:
 * RAM read port is $1080 - $10FF, write port is $1000 - $107F.
 */
void emulate_FxSC_cartridge(uint16_t lowBS, uint16_t highBS, int isSC)
{
	setup_cartridge_image_with_ram();

	__disable_irq();	// Disable interrupts
	uint16_t addr, addr_prev = 0, data = 0, data_prev = 0;
	unsigned char *bankPtr = &cart_rom[0];

	while (1)
	{
		while ((addr = ADDR_IN) != addr_prev)
			addr_prev = addr;
		// got a stable address
		if (addr & 0x1000)
		{ // A12 high
			if (addr >= lowBS && addr <= highBS)	// bank-switch
				bankPtr = &cart_rom[(addr-lowBS)*4*1024];

			if (isSC && (addr & 0x1F00) == 0x1000)
			{	// SC RAM access
				if (addr & 0x0080)
				{	// a read from cartridge ram
					DATA_OUT = ((uint16_t)cart_ram[addr&0x7F])<<8;
					SET_DATA_MODE_OUT
					// wait for address bus to change
					while (ADDR_IN == addr) ;
					SET_DATA_MODE_IN
				}
				else
				{	// a write to cartridge ram
					// read last data on the bus before the address lines change
					while (ADDR_IN == addr) { data_prev = data; data = DATA_IN; }
					cart_ram[addr&0x7F] = data_prev>>8;
				}
			}
			else
			{	// normal rom access
				DATA_OUT = ((uint16_t)bankPtr[addr&0xFFF])<<8;
				SET_DATA_MODE_OUT
				// wait for address bus to change
				while (ADDR_IN == addr) ;
				SET_DATA_MODE_IN
			}
		}
	}
	__enable_irq();
}

/* FA (CBS RAM plus) Bankswitching
 * -------------------------------
 * Similar to the above, but with 3 ROM banks for a total of 12K
 * plus 256 bytes of RAM:
 * RAM read port is $1100 - $11FF, write port is $1000 - $10FF.
 */
void emulate_FA_cartridge()
{
	setup_cartridge_image_with_ram();

	__disable_irq();	// Disable interrupts
	uint16_t addr, addr_prev = 0, data = 0, data_prev = 0;
	unsigned char *bankPtr = &cart_rom[0];

	while (1)
	{
		while ((addr = ADDR_IN) != addr_prev)
			addr_prev = addr;
		// got a stable address
		if (addr & 0x1000)
		{ // A12 high
			if (addr >= 0x1FF8 && addr <= 0x1FFA)	// bank-switch
				bankPtr = &cart_rom[(addr-0x1FF8)*4*1024];

			if ((addr & 0x1F00) == 0x1100)
			{	// a read from cartridge ram
				DATA_OUT = ((uint16_t)cart_ram[addr&0xFF])<<8;
				SET_DATA_MODE_OUT
				// wait for address bus to change
				while (ADDR_IN == addr) ;
				SET_DATA_MODE_IN
			}
			else if ((addr & 0x1F00) == 0x1000)
			{	// a write to cartridge ram
				// read last data on the bus before the address lines change
				while (ADDR_IN == addr) { data_prev = data; data = DATA_IN; }
				cart_ram[addr&0xFF] = data_prev>>8;
			}
			else
			{	// normal rom access
				DATA_OUT = ((uint16_t)bankPtr[addr&0xFFF])<<8;
				SET_DATA_MODE_OUT
				// wait for address bus to change
				while (ADDR_IN == addr) ;
				SET_DATA_MODE_IN
			}
		}
	}
	__enable_irq();
}

/* FE Bankswitching
 * ----------------
 * The text below is quoted verbatim from the source code of the Atari
 * 2600 emulator Stella (https://github.com/stella-emu) which was the
 * best reference that I could find for FE bank-switching.
 * The implementation below is based on this description, and the relevant
 * source files in Stella.
 */
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
int main(void)
{
	char curPath[256] = "";
	int cart_type = CART_TYPE_NONE;

	init();
	/* In/Out: PE{8..15} */
	config_gpio_data();
	/* In: PD{0..15} */
	config_gpio_addr();
	/* In: Other Cart Input Signals - PC{0..1} */
	config_gpio_sig();

	if (!(GPIOC->IDR & 0x0001))
		tv_mode = TV_MODE_PAL60;
	else if (!(GPIOC->IDR & 0x0002))
		tv_mode = TV_MODE_PAL;
	else
		tv_mode = TV_MODE_NTSC;

	set_tv_mode(tv_mode);

	// set up status area
	set_menu_status_msg("BY R.EDWARDS");
	set_menu_status_byte(0);



	while (1) {
		int ret = emulate_firmware_cartridge();

		if (ret == CART_CMD_ROOT_DIR)
		{
			curPath[0] = 0;
			if (!readDirectoryForAtari(curPath))
				set_menu_status_msg("CANT READ SD");
		}
		else
		{
			int sel = ret - CART_CMD_SEL_ITEM_n;
			DIR_ENTRY *d = &dir_entries[sel];

			if (d->isDir)
			{	// selection is a directory
				if (!strcmp(d->filename, ".."))
				{	// go back
					int len = strlen(curPath);
					while (len && curPath[--len] != '/');
					curPath[len] = 0;
				}
				else
				{	// go into director
					strcat(curPath, "/");
					strcat(curPath, d->filename);
				}

				if (!readDirectoryForAtari(curPath))
					set_menu_status_msg("CANT READ SD");
				Delayms(200);
			}
			else
			{	// selection is a rom file
				strcpy(cartridge_image_path, curPath);
				strcat(cartridge_image_path, "/");
				strcat(cartridge_image_path, d->filename);
				cart_type = identify_cartridge(cartridge_image_path);
				Delayms(200);
				if (cart_type != CART_TYPE_NONE)
					emulate_cartridge(cart_type);
				else
					set_menu_status_msg("BAD ROM FILE");
			}
		}
	}
}

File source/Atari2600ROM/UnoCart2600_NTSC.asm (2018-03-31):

; UnoCart2600 Menu
;   by Robin Edwards (Electrotrains) 2018
; NTSC Version of Firmware
; Version History
; ---------------
; v1.01 25/1/18 Added Select/Reset as alternative to joysitck for menu navigation
; v1.02 28/3/18 Adds read to $1FF4 on init, to unlock the comms area on the cartridge

; @com.wudsn.ide.asm.hardware=ATARI2600
	icl "vcs.asm"
	icl "macro.asm"

;--------------------------TIA CONSTANTS----------------------------------

;--NUSIZx CONSTANTS
;	player:
ONECOPYNORMAL		=	$00
TWOCOPIESCLOSE		=	$01
TWOCOPIESMED		=	$02
THREECOPIESCLOSE	=	$03
TWOCOPIESWIDE		=	$04
ONECOPYDOUBLE		=	$05
THREECOPIESMED		=	$06
ONECOPYQUAD		=	$07
;---HMxx CONSTANTS
LEFTSEVEN		=	$70
LEFTSIX			=	$60
LEFTFIVE		=	$50
LEFTFOUR		=	$40
LEFTTHREE		=	$30
LEFTTWO			=	$20
LEFTONE			=	$10
NOMOVEMENT		=	$00
RIGHTONE		=	$F0
RIGHTTWO		=	$E0
RIGHTTHREE		=	$D0
RIGHTFOUR		=	$C0
RIGHTFIVE		=	$B0
RIGHTSIX		=	$A0
RIGHTSEVEN		=	$90
RIGHTEIGHT		=	$80

;------------------------------------------------------------------
; colour scheme
;------------------------------------------------------------------
TITLE_BK_COL =		$94	
TITLE_COL =		$9e
STATUS_BK_COL =		$04	
STATUS_COL =		$0e
MENU_BK_COL =		$80	
MENU_ITEM_COL =		$0e
MENU_FOLDER_COL	=	$9a
MENU_FOLDER_BK_COL =	$80
MENU_SEL_COL =		$ce
MENU_SEL_BK_COL =	$c2
;------------------------------------------------------------------
; atari->cart comms addresses
;------------------------------------------------------------------
CART_CMD_SEL_ITEM_n = 	$1E00	// out
CART_CMD_ROOT_DIR = 	$1EF0	// out
CART_CMD_START_CART = 	$1EFF	// out

WaitCart = $84 ; routine to run from 2600 RAM while cart busy copied here
ITEMS_PER_SCREEN = 7
;------------------------------------------------------------------
; non-volatile memory $80-$83
;------------------------------------------------------------------
	org $80
CurItem		.ds 1; current item selected in the menu
;------------------------------------------------------------------
; volatile memory ($88+) overwritten by RAM routine        
;------------------------------------------------------------------
	org $88
Counter		.ds 2
TextBlockPointer	.ds 2
TextLineCounter	.ds 1
Char1Ptr	.ds 2
Char2Ptr	.ds 2
Char3Ptr	.ds 2
Char4Ptr	.ds 2
Char5Ptr	.ds 2
Char6Ptr	.ds 2
Char7Ptr	.ds 2
Char8Ptr	.ds 2
Char9Ptr	.ds 2
Char10Ptr	.ds 2
Char11Ptr	.ds 2
Char12Ptr	.ds 2
Temp		.ds 1
ItemTextPtr	.ds 2
ItemCount	.ds 1	; total # of items
TopItem		.ds 1	; item # at the top of the page
RowItem		.ds 1	; item # we are drawing
RowCount	.ds 1	; 0 ->  ITEMS_PER_SCREEN-1
StickDelayCount	.ds 1
;------------------------------------------------------------------
; Cartridge ROM
;------------------------------------------------------------------
	opt h-f+l+		;Create plain 4k ROM file
	org $f000		;Main part

	.proc cart
Start
	cld			;Clear decimal flag
	lda #0
	tax
init	sta $00,x		;Clear TIA ($00-$3f) and 128 bytes of RAM ($80-$ff)
	inx
	bne init
	dex
	txs			;Set stack pointer to $ff

; multicart init
	; the firmware looks for an access to $1FF4 before unlocking the comms area ($1Exx).
	; this is because the 7800 firmware accesses this area on power-up, and we want to ignore
	; these reads until the 7800 has started the cart in 2600 mode.
	lda $1FF4
	
	jsr PrepareWaitCartRoutine
	ldx #$F0 ; CART_CMD_ROOT_DIR
	jsr WaitCart
	
; main sd navigation loop
loop	jsr InitMenu
	jsr Menu
	
; an item has been selected from the menu
	jsr PrepareWaitCartRoutine
	ldx CurItem
	jsr WaitCart
	jmp loop
;------------------------------------------------------------------
; Menu
;------------------------------------------------------------------
	.proc InitMenu
	lda #0
	sta StickDelayCount
	sta CurItem
	sta TopItem
	sta ItemCount
	
	; count items
	mwa #ItemsList ItemTextPtr
        ldy #0
NextItem
        ; check if null string
        lda (ItemTextPtr),y
	beq DoneItems
	clc
	adw ItemTextPtr #12
	inc ItemCount
	lda ItemCount
	bne NextItem
DoneItems
	rts
	.endp
;------------------------------------------------------------------
	.proc ReadControls
	lda StickDelayCount
	beq _0
	dec StickDelayCount
	rts
_0
	; check down
	lda #$20
	and swcha
	beq _0X
	; check select
	lda #$02
	and swchb
	beq _0X
	jmp _1
_0X	; down/select pressed
	ldx CurItem
	inx
	cpx ItemCount
	beq _1
	inc CurItem
	lda #10
	sta StickDelayCount
	
_1	; check up
	lda #$10
	and swcha
	bne _2
	; up pressed
	ldx CurItem
	beq _2
	dec CurItem
	lda #10
	sta StickDelayCount

_2	; check left
	lda #$40
	and swcha
	bne _3
	; left pressed
	lda CurItem
	cmp #ITEMS_PER_SCREEN
	bcc _3
	sec
	sbc #ITEMS_PER_SCREEN
	sta CurItem
	lda #10
	sta StickDelayCount
	
_3	; check right
	lda #$80
	and swcha
	bne _4
	; right pressed
	lda CurItem
	clc
	adc #ITEMS_PER_SCREEN
	cmp ItemCount
	bcc _3a
	ldy ItemCount
	dey
	tya
_3a	sta CurItem
	lda #10
	sta StickDelayCount
_4
	rts
	.endp
;------------------------------------------------------------------
	.proc Menu       
        
        ; use the playfield to mask the player artifacts
        lda #0
        sta COLUPF
        lda #$70
        sta PF0
        lda #0
        sta PF1
        lda #0
        sta PF2
        lda #1
        sta CTRLPF

NextFrame
; VBlank ------------------------------------------------------------------
	lda #2
	sta vblank
	sta vsync
	sta wsync
	sta wsync
	sta wsync
	lda #0
	sta vsync
	
	TIMER_SETUP 37
        jsr ReadControls
        
        dec Counter
       	lda #1
	sta VDELP0
	sta VDELP1
	lda #THREECOPIESMED
	sta NUSIZ0
	sta NUSIZ1
	lda #$15
	ldx #0
	jsr PositionASpriteSubroutine
	lda #$25
	ldx #1
	jsr PositionASpriteSubroutine
	
; from the current item, set topItem and the item text pointer
	mwa #ItemsList ItemTextPtr
	lda #0
       	sta TextLineCounter
       	sta TopItem
	lda CurItem
	sta Temp

@	sec
	sbc #ITEMS_PER_SCREEN
	bmi DoneTopItem
	sta Temp
	lda TopItem
	clc
	adc #ITEMS_PER_SCREEN
	sta TopItem
	adw ItemTextPtr #(ITEMS_PER_SCREEN*12)
	lda Temp
	jmp @-
DoneTopItem

	sta wsync
        TIMER_WAIT
        sta wsync
	lda #0
	sta wsync
	sta vblank
	sta wsync	
; Frame ------------------------------------------------------------------
	TIMER_SETUP 192
	
; menu heading
	mwa #MenuTitle TextBlockPointer
	lda #0
       	sta TextLineCounter        
  	jsr SetTextPointersSubroutine
	lda #TITLE_COL
	sta COLUP0
	sta COLUP1
	lda #TITLE_BK_COL
	sta wsync
	sta COLUBK
  	jsr DrawLineOfTextSubroutine

; items  	
; start of item loop
	lda #0
	sta RowCount
       	sta TextLineCounter        
       	
	lda #0
	sta wsync
	sta COLUBK
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

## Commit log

2018-01-27 add breakout pcb
    [breakout.brd]
2018-02-26 Replace stricmp with strcasecmp.
    [main.c]
2018-02-26 Makefile for plan build with ARM cortex toolchain.
2018-03-06 More refactoring, more SC stuff.
    * Initial supercharger setup
    * Rework firmware emulation to enable setup tasks at the beginning
    of cartridge emulation
    [cartridge_io.h, main.c]
2018-03-07 Assorted bugfixes -> supercharger works as advertised.
    [main.c]
2018-03-16 Code style: switch to tabs.
2018-03-16 Track dependencies in make build.
2018-03-21 bug fixes
    fix file extension->cart type
    [main.c]

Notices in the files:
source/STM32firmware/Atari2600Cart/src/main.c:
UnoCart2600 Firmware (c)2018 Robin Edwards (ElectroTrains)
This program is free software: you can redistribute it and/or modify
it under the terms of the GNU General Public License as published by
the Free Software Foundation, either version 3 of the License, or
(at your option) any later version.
